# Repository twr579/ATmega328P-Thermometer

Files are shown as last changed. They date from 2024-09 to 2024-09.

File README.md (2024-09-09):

# ATmega328P Thermometer
This repository contains code, PCB, and enclosure design for a thermometer based on the ATmega328P microcontroller.

I was inspired to work on this project because of my lack of a portable, lightweight thermometer to take on hiking/camping trips. I've previously relied on my phone's weather app and woken up with a frost-covered sleeping bag as a result, so having a thermometer on hand is a useful tool for testing the efficacy of my sleep system.

The code was written  and tested in Arduino IDE.

Schematic and PCB were designed in KiCad.

Enclosure was designed in Fusion 360.

## List of Materials
* [ATmega328P-PU](https://www.digikey.com/en/products/detail/microchip-technology/ATMEGA328P-PU/1914589)
* [JST 2-pin Connector Header](https://www.digikey.com/en/products/detail/jst-sales-america-inc/S2B-PH-K-S/926626)
* [Lithium Ion Polymer Battery - 3.7v 500mAh](https://www.adafruit.com/product/1578)
* [Right Angle Slide Switch](https://www.digikey.com/en/products/detail/c-k/OS102011MA1QN1/1981430)
* [L4931CZ33-AP Voltage Regulator](https://www.digikey.com/en/products/detail/stmicroelectronics/L4931CZ33-AP/1038129)
* [16MHz Crystal Oscillator](https://www.sparkfun.com/products/536)
* [Temperature Sensor - TMP36](https://www.sparkfun.com/products/10988)
* 2x Single Digit 7-segment Display
* 3x 10uF Electrolytic Capacitor
* 2x 22pF Ceramic Capacitor
* 10k Ohm Resistor

## Schematic
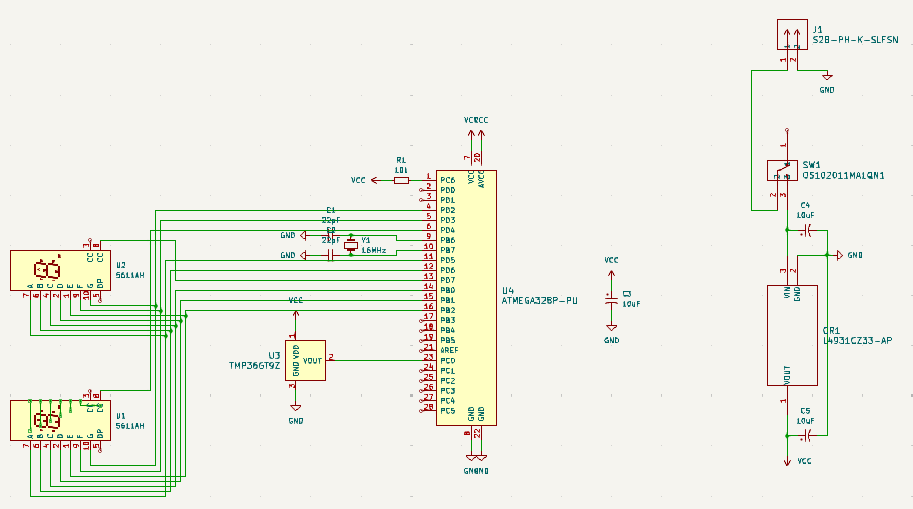
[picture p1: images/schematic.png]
Schematic


## PCB
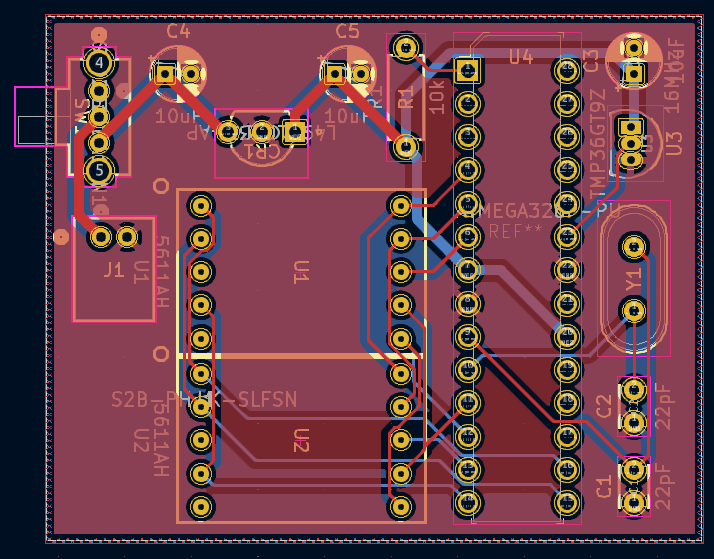
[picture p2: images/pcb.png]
PCB


## 3D Model
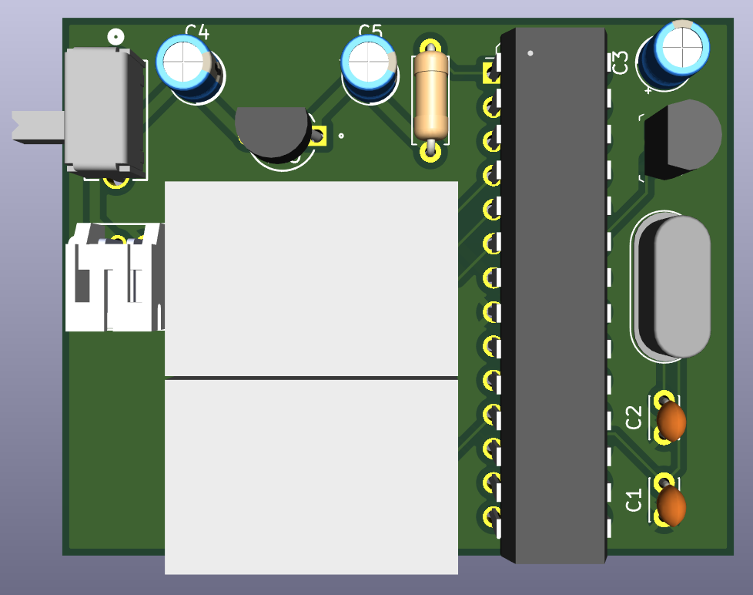
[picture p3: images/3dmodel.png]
3D Model


## Enclosure
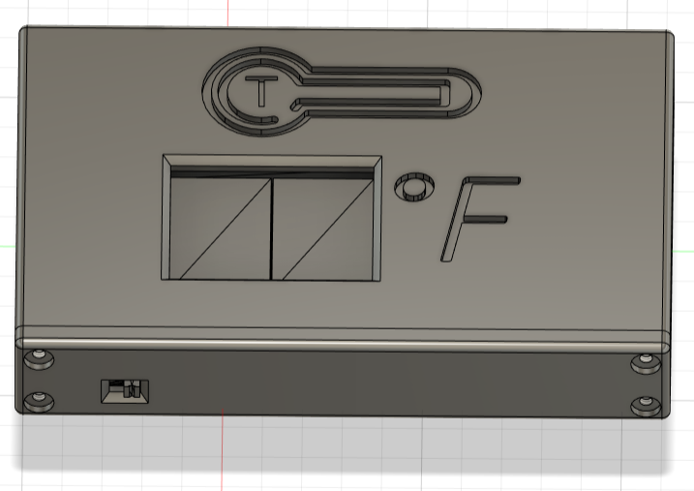
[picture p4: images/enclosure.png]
Enclosure


## Final Product - Without Enclosure
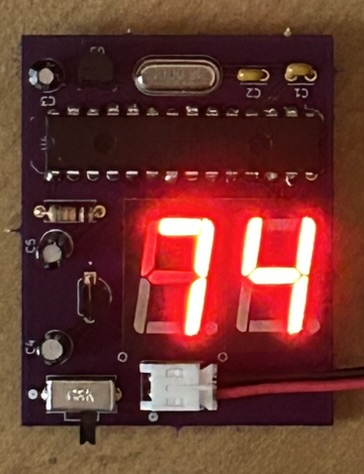
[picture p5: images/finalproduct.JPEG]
Final Product without Enclosure


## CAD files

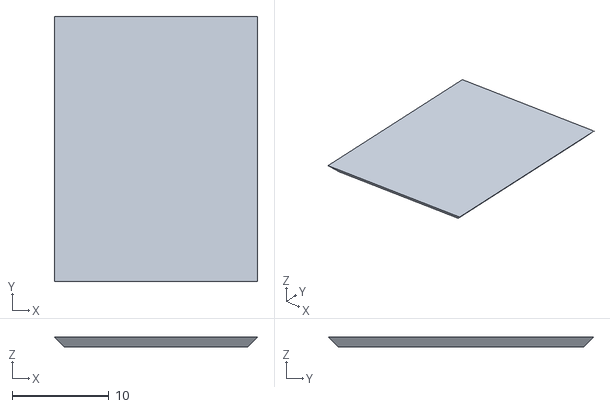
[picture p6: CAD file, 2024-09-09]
box/Box - Window.stl
21.0 x 27.4 x 1.00

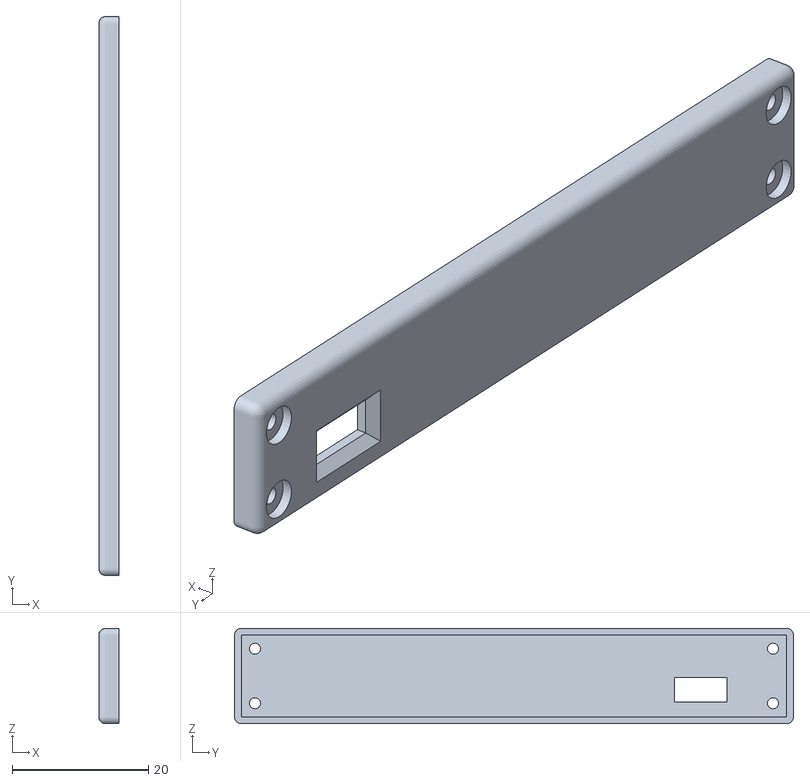
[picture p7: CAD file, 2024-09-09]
box/Box - Bottom.stl
3.00 x 82.0 x 14.0

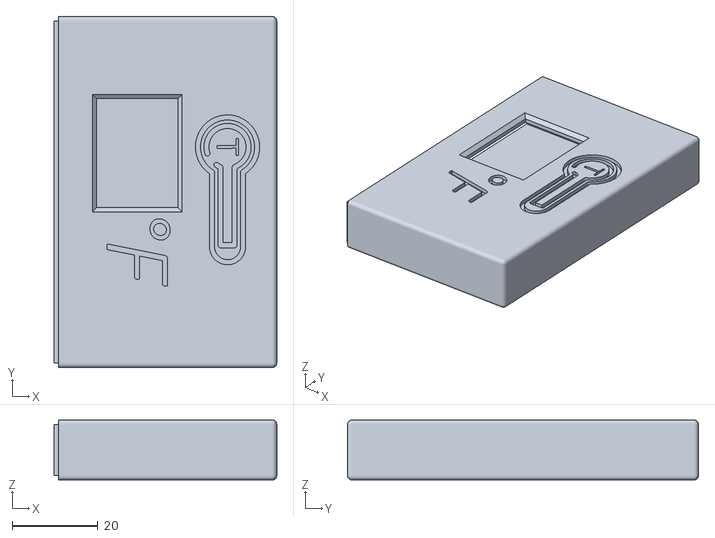
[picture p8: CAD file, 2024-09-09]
box/Box - Top.stl
52.0 x 82.0 x 14.0

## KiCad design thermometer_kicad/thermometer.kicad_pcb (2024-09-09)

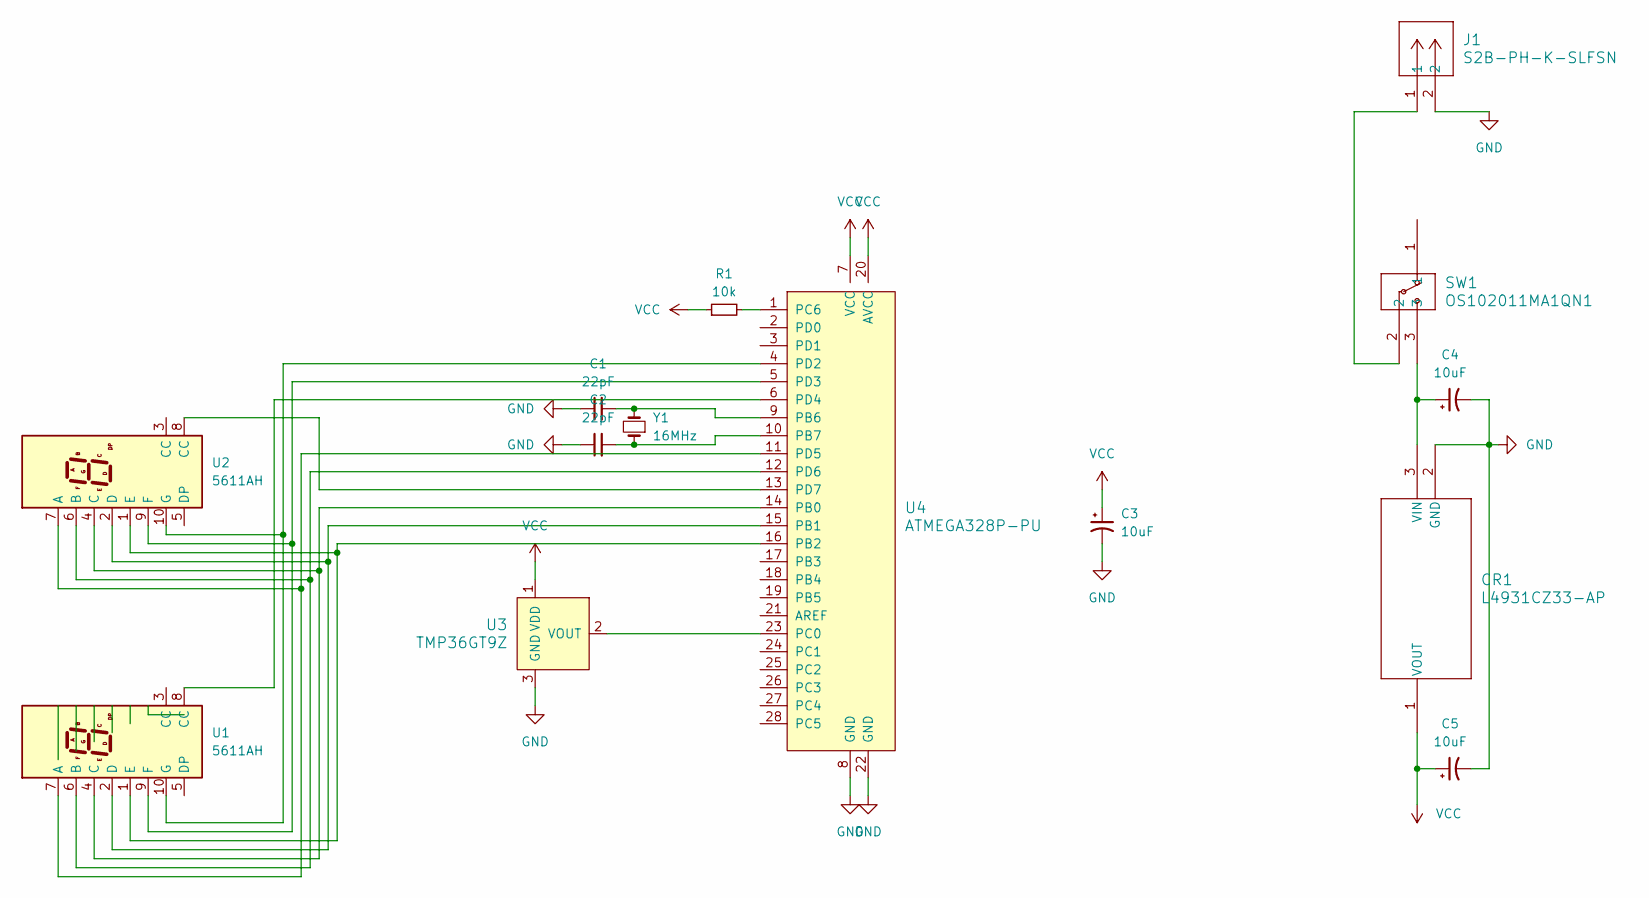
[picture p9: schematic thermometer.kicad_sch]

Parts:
C1, C2: 22pF; C_Disc_D3.0mm_W2.0mm_P2.50mm
C3, C4, C5: 10uF; CP_Radial_D4.0mm_P2.00mm
CR1: L4931CZ33-AP; TO-92-TR_STM
J1: S2B-PH-K-SLFSN; CONN_S2B-PH-K-S_JST
R1: 10k; R_Axial_DIN0207_L6.3mm_D2.5mm_P7.62mm_Horizontal
SW1: OS102011MA1QN1; OS102011MA1QN1_CNK
U1, U2: 5611AH
U3: TMP36GT9Z; TO-92-3; MPN TMP36GT9Z; Digi-Key_PN TMP36GT9Z-ND
U4: ATMEGA328P-PU; DIP-28_W7.62mm; MPN ATMEGA328P-PU; Digi-Key_PN ATMEGA328P-PU-ND
Y1: 16MHz; Crystal_HC49-U_Vertical

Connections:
GND: C1.1, C2.1, C3.2, C4.2, C5.2, CR1.2 (GND), J1.2, U3.3 (GND), U4.8 (GND), U4.22 (GND)
unnamed: C4.1, CR1.3 (VIN), SW1.3
unnamed: J1.1, SW1.2
unnamed: U1.7 (A), U2.7 (A), U4.11 (PD5)
unnamed: U1.6 (B), U2.6 (B), U4.12 (PD6)
unnamed: U1.4 (C), U2.4 (C), U4.14 (PB0)
unnamed: U1.2 (D), U2.2 (D), U4.15 (PB1)
unnamed: U1.1 (E), U2.1 (E), U4.16 (PB2)
unnamed: U1.9 (F), U2.9 (F), U4.5 (PD3)
unnamed: U1.10 (G), U2.10 (G), U4.4 (PD2)
unnamed: U3.2 (VOUT), U4.23 (PC0)
unnamed: C1.2, U4.9 (PB6), Y1.2
unnamed: C2.2, U4.10 (PB7), Y1.1
unnamed: R1.2, U4.1 (PC6)
unnamed: U1.8 (CC), U4.6 (PD4)
unnamed: U2.8 (CC), U4.13 (PD7)
VCC: C3.1, C5.1, CR1.1 (VOUT), R1.1, U3.1 (VDD), U4.7 (VCC), U4.20 (AVCC)

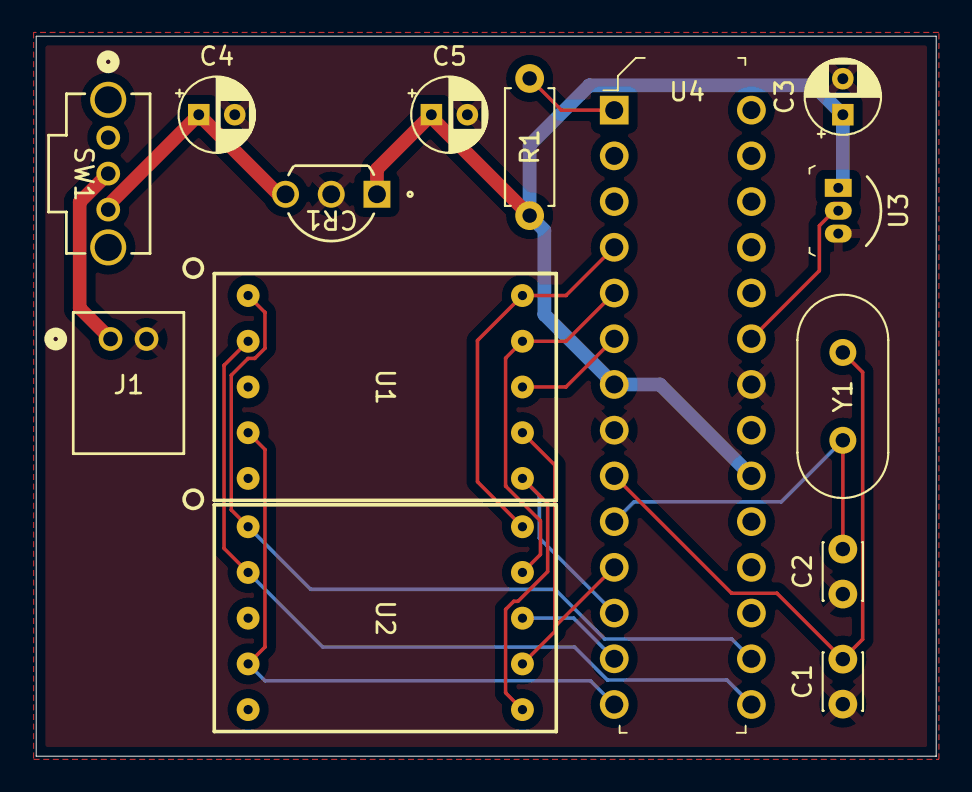
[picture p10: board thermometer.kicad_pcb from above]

Board: 2 copper layers, 50.0 x 40.0 mm, 14 parts (0 on the bottom side), 17 nets.

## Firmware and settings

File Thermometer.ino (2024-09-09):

#include <Arduino_FreeRTOS.h>

// These constants won't change. They're used to give names to the pins used:
const int analogInPin = A0;  // Analog input pin that the sensor is attached to
byte pin[] = { 5, 6, 8, 9, 10, 3, 2 };
int number[10][7] = {
  { 1, 1, 1, 1, 1, 1, 0, }, // 0
  { 0, 1, 1, 0, 0, 0, 0, }, // 1
  { 1, 1, 0, 1, 1, 0, 1, }, // 2
  { 1, 1, 1, 1, 0, 0, 1, }, // 3
  { 0, 1, 1, 0, 0, 1, 1, }, // 4
  { 1, 0, 1, 1, 0, 1, 1, }, // 5
  { 1, 0, 1, 1, 1, 1, 1, }, // 6
  { 1, 1, 1, 0, 0, 0, 0, }, // 7
  { 1, 1, 1, 1, 1, 1, 1, }, // 8
  { 1, 1, 1, 1, 0, 1, 1, }, // 9
};
int D1 = 4;
int D2 = 7;
volatile int tens = 0;
volatile int ones = 0;

void Task_UpdateTens(void *param);
void Task_UpdateOnes(void *param);
void Task_UpdateReadings(void *param);

TaskHandle_t Task_Handle1;
TaskHandle_t Task_Handle2;
TaskHandle_t Task_Handle3;

void setup() {
  for (byte i = 0; i < 8; i++) {
    pinMode(pin[i], OUTPUT);
  }
  pinMode(D1, OUTPUT);
  pinMode(D2, OUTPUT);

  xTaskCreate(Task_UpdateTens,"Task1",100,NULL,1,&Task_Handle1);
  xTaskCreate(Task_UpdateOnes,"Task2",100,NULL,1,&Task_Handle2);
  xTaskCreate(Task_UpdateReadings,"Task3",100,NULL,2,&Task_Handle3);
}

void loop() {
}

void Task_UpdateTens(void *param) {
  (void) param;

  while(1) {
    digitalWrite(D1, LOW);
    digitalWrite(D2, HIGH);
    for (byte i = 0; i < 8; i++) {
      digitalWrite(pin[i], number[tens][i]);
    }
    delay(1);
  }
}

void Task_UpdateOnes(void *param) {
  (void) param;

  while(1) {
    digitalWrite(D1, HIGH);
    digitalWrite(D2, LOW);
    for (byte i = 0; i < 8; i++) {
      digitalWrite(pin[i], number[ones][i]);
    }
    delay(1);
  }
}

void Task_UpdateReadings(void *param) {
  (void) param;
  TickType_t getTick;
  getTick = xTaskGetTickCount();

  while(1) {
    // read the analog in value:
    int sensorValue = analogRead(analogInPin);
    double outputValue = sensorValue / 1023.0 * 3.3;

    double degreesC = (outputValue - 0.5) * 100.0;
    int degreesF = degreesC * (9.0/5.0) + 32.0;
    tens = degreesF / 10;
    ones = degreesF % 10;

    vTaskDelayUntil(&getTick, 30000/portTICK_PERIOD_MS);
  }
}
